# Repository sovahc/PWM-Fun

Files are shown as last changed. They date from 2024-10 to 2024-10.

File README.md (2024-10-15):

# PWM-Fun
PWM fan controller for water cooled PC
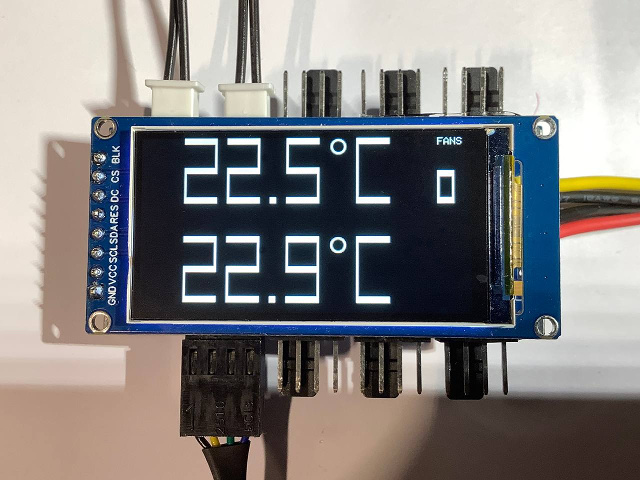
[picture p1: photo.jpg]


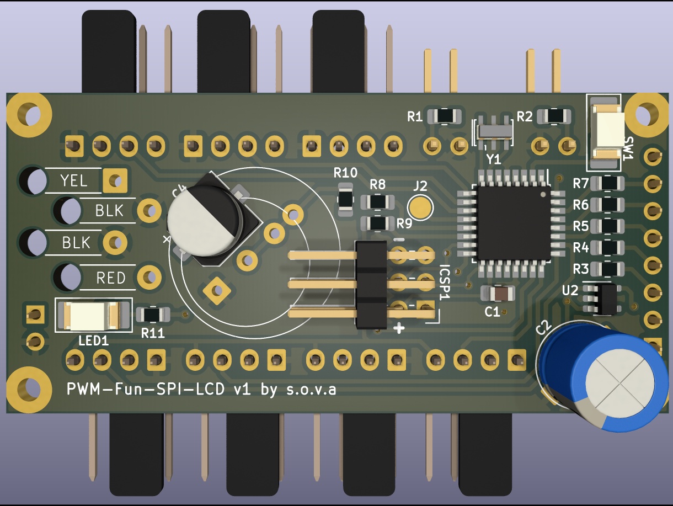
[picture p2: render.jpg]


I didn't find the fan controller cheap and cute, so I made it myself.

For building minimal LCD version of this project you need:
* PCB (use Kicad to export gerber files for manufacturing)
* 170x320 SPI LCD (they are cheap and slow)
* ATMega328 microcontroller
* 2.54mm single row 8 pin male + female connector (I recommend short L7.5 version)
* 2x SMD 10k resistor (R1, R2)
* 7x SMD 220 Ohm resistor (R3 - R9)
* SMD 100 nF capacitor (C1)
* SMD(or not) 4.7 uF capacitor (C2)
* 7x angled PC Fan connector  
* M2.5 screws and nuts for mounting.
* SATA to Molex adapter (Not Molex to SATA!)

Equipment:
* Any AVR programmer (You can use any usb arduino board with sketch ArduinoISP, don't forget to press "Upload Using Programmer")
* Good soldering iron recomended.

You can add buzzer and 500 Ohm resistor if you like.

You can add WS2812 strip if you like.

You can use the ATmega internal oscillator if you are not using the WS2812.

Don't forget to short J1 if you not use U2 (probably you don't need U2)

The fans speed is controlled by the thermal sensor 1. The thermal sensor 2 is set to 50°C alarm. I use it to control the temperature of 12VHPWR connector 🩹

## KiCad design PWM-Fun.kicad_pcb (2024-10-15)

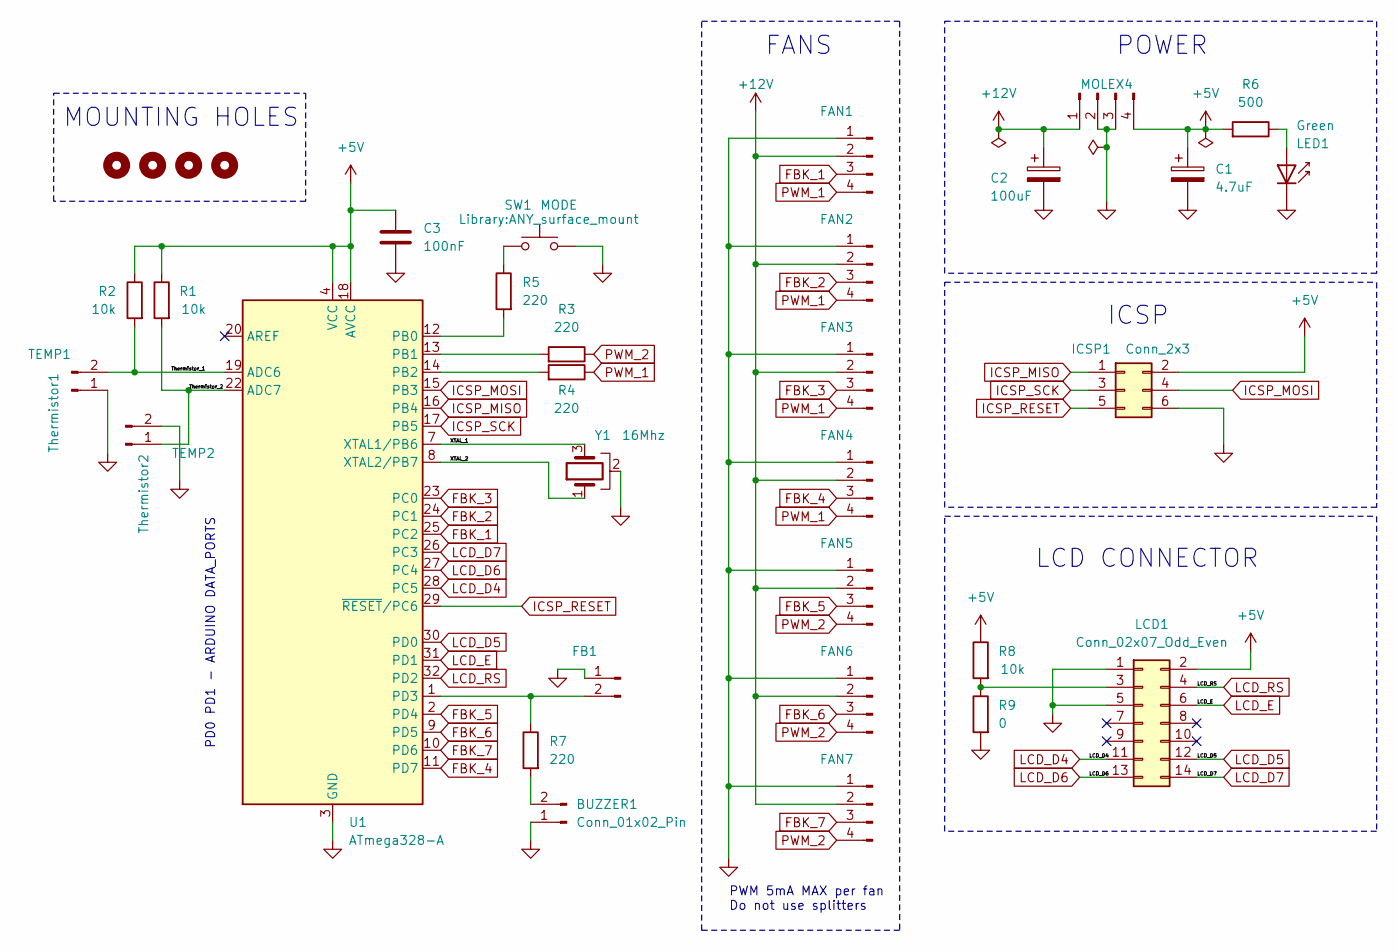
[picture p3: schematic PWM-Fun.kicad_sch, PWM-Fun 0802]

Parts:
BUZZER1: Conn_01x02_Pin; My_buzzer
C1: 4.7uF; Multicap
C2: 100uF; Multicap
C3: 100nF; C_0805_2012Metric_Pad1.18x1.45mm_HandSolder
FAN1, FAN2, FAN3, FAN4, FAN5, FAN6, FAN7: FanPinHeader_1x04_P2.54mm_Vertical_custom
FB1: TO_PC; PinSocket_1x02_P2.54mm_Vertical
H1, H2, H3, H4: MountingHole_Pad; Slot 2.5x1.27
ICSP1: Conn_2x3; PinHeader_2x03_P2.54mm_Horizontal
LCD1: Conn_02x07_Odd_Even; LCD_Connector_2x07_P2.54mm_Vertical
LED1: Green; ANY_surface_mount
MOLEX4: Conn_01x04_Pin; SolderWire-1-2_compact
R1, R2, R8: 10k; R_0805_2012Metric_Pad1.20x1.40mm_HandSolder
R3, R4, R5, R7: 220; R_0805_2012Metric_Pad1.20x1.40mm_HandSolder
R6: 500; R_0805_2012Metric_Pad1.20x1.40mm_HandSolder
R9: 0; R_0805_2012Metric_Pad1.20x1.40mm_HandSolder
SW1: MODE; ANY_surface_mount
TEMP1: Thermistor1; PinHeader_1x02_P2.54mm_Horizontal
TEMP2: Thermistor2; PinHeader_1x02_P2.54mm_Horizontal
U1: ATmega328-A; TQFP-32_7x7mm_P0.8mm
Y1: 16Mhz; Resonator_SMD_Murata_CSTxExxV-3Pin_3.0x1.1mm_HandSoldering

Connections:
+5V: C1.1, C3.1, ICSP1.2, LCD1.2, MOLEX4.4, R1.1, R2.1, R6.2, R8.1, U1.4 (VCC), U1.6 (VCC), U1.18 (AVCC)
+12V: C2.1, FAN1.2, FAN2.2, FAN3.2, FAN4.2, FAN5.2, FAN6.2, FAN7.2, MOLEX4.1
/Thermistor_1: R2.2, TEMP1.2, U1.19 (ADC6)
/Thermistor_2: R1.2, TEMP2.1, U1.22 (ADC7)
/XTAL_1: U1.7 (XTAL1/PB6), Y1.3
/XTAL_2: U1.8 (XTAL2/PB7), Y1.1
FBK_1: FAN1.3, U1.25 (PC2)
FBK_2: FAN2.3, U1.24 (PC1)
FBK_3: FAN3.3, U1.23 (PC0)
FBK_4: FAN4.3, U1.11 (PD7)
FBK_5: FAN5.3, U1.2 (PD4)
FBK_6: FAN6.3, U1.9 (PD5)
FBK_7: FAN7.3, U1.10 (PD6)
GND: BUZZER1.1, C1.2, C2.2, C3.2, FAN1.1, FAN2.1, FAN3.1, FAN4.1, FAN5.1, FAN6.1, FAN7.1, FB1.1, ICSP1.6, LCD1.1, LCD1.5, LED1.1 (K), MOLEX4.2, MOLEX4.3, R9.2, SW1.2, TEMP1.1, TEMP2.2, U1.3 (GND), U1.5 (GND), U1.21 (GND), Y1.2
ICSP_MISO: ICSP1.1, U1.16 (PB4)
ICSP_MOSI: ICSP1.4, U1.15 (PB3)
ICSP_RESET: ICSP1.5, U1.29 (~RESET/PC6)
ICSP_SCK: ICSP1.3, U1.17 (PB5)
LCD_D4: LCD1.11, U1.28 (PC5)
LCD_D5: LCD1.12, U1.30 (PD0)
LCD_D6: LCD1.13, U1.27 (PC4)
LCD_D7: LCD1.14, U1.26 (PC3)
LCD_E: LCD1.6, U1.31 (PD1)
LCD_RS: LCD1.4, U1.32 (PD2)
unnamed: BUZZER1.2, R7.2
unnamed: FB1.2, R7.1, U1.1 (PD3)
unnamed: LCD1.3, R8.2, R9.1
unnamed: LED1.2 (A), R6.1
unnamed: R5.1, SW1.1
unnamed: R5.2, U1.12 (PB0)
unnamed: R3.2, U1.13 (PB1)
unnamed: R4.2, U1.14 (PB2)
PWM_1: FAN1.4, FAN2.4, FAN3.4, FAN4.4, R4.1
PWM_2: FAN5.4, FAN6.4, FAN7.4, R3.1

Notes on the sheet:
MOUNTING HOLES
FANS
ICSP
PD0 PD1 - ARDUINO DATA_PORTS
LCD CONNECTOR
PWM 5mA MAX per fan Do not use splitters
POWER

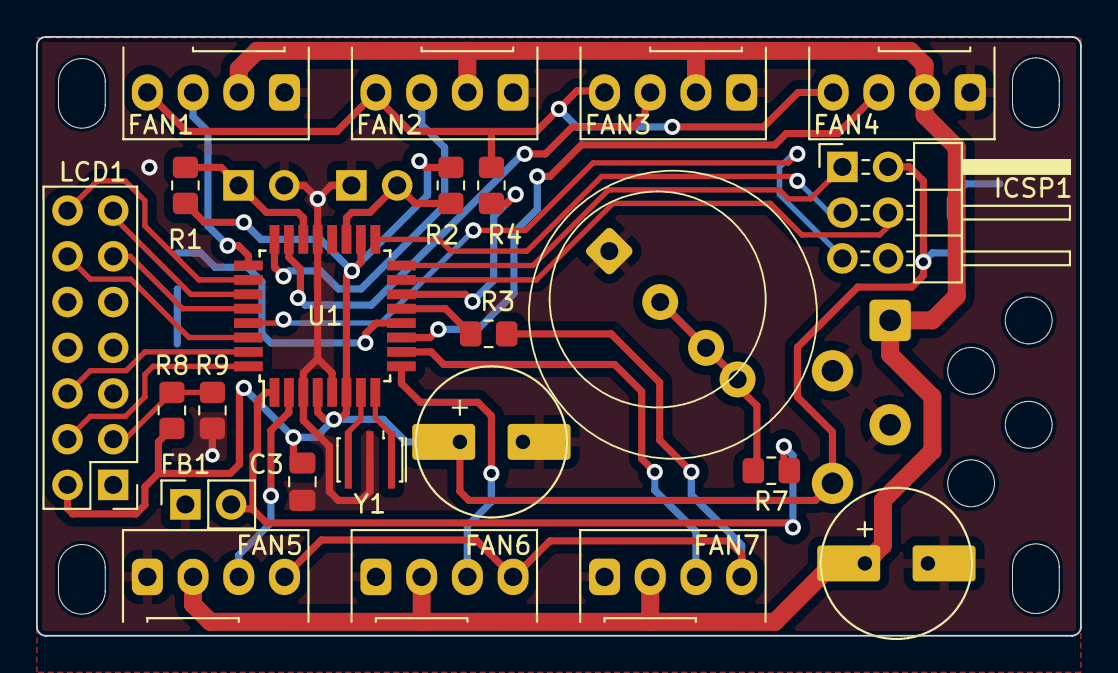
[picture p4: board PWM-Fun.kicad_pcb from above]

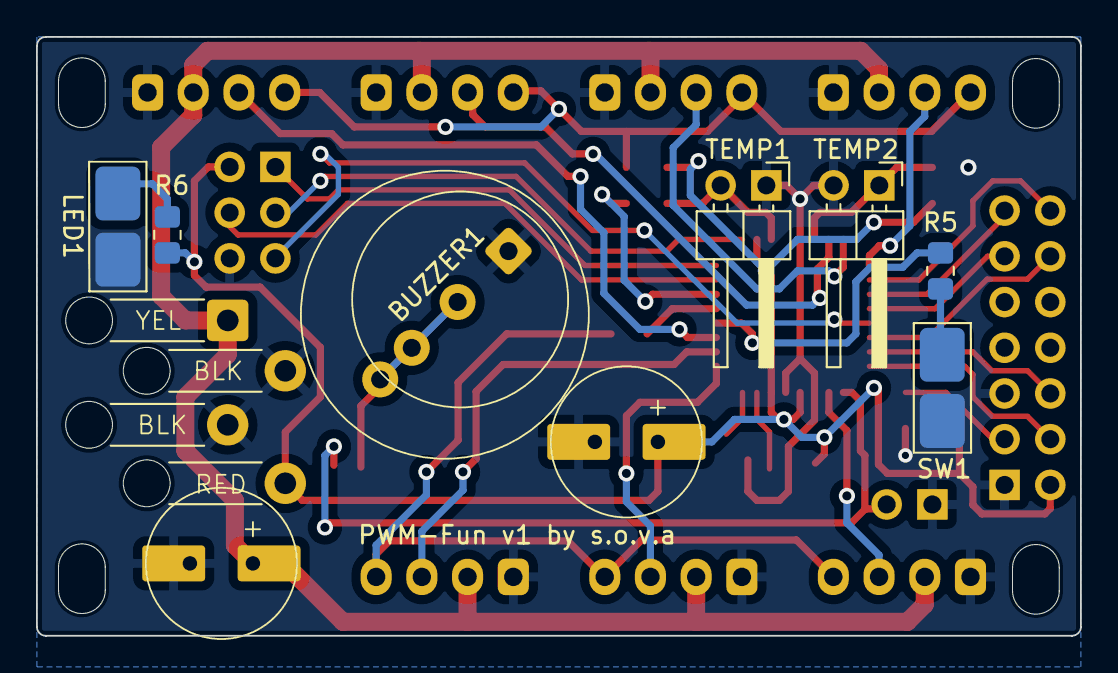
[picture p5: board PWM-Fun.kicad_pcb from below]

Board: 2 copper layers, 58.0 x 33.3 mm, 34 parts (8 on the bottom side), 34 nets.

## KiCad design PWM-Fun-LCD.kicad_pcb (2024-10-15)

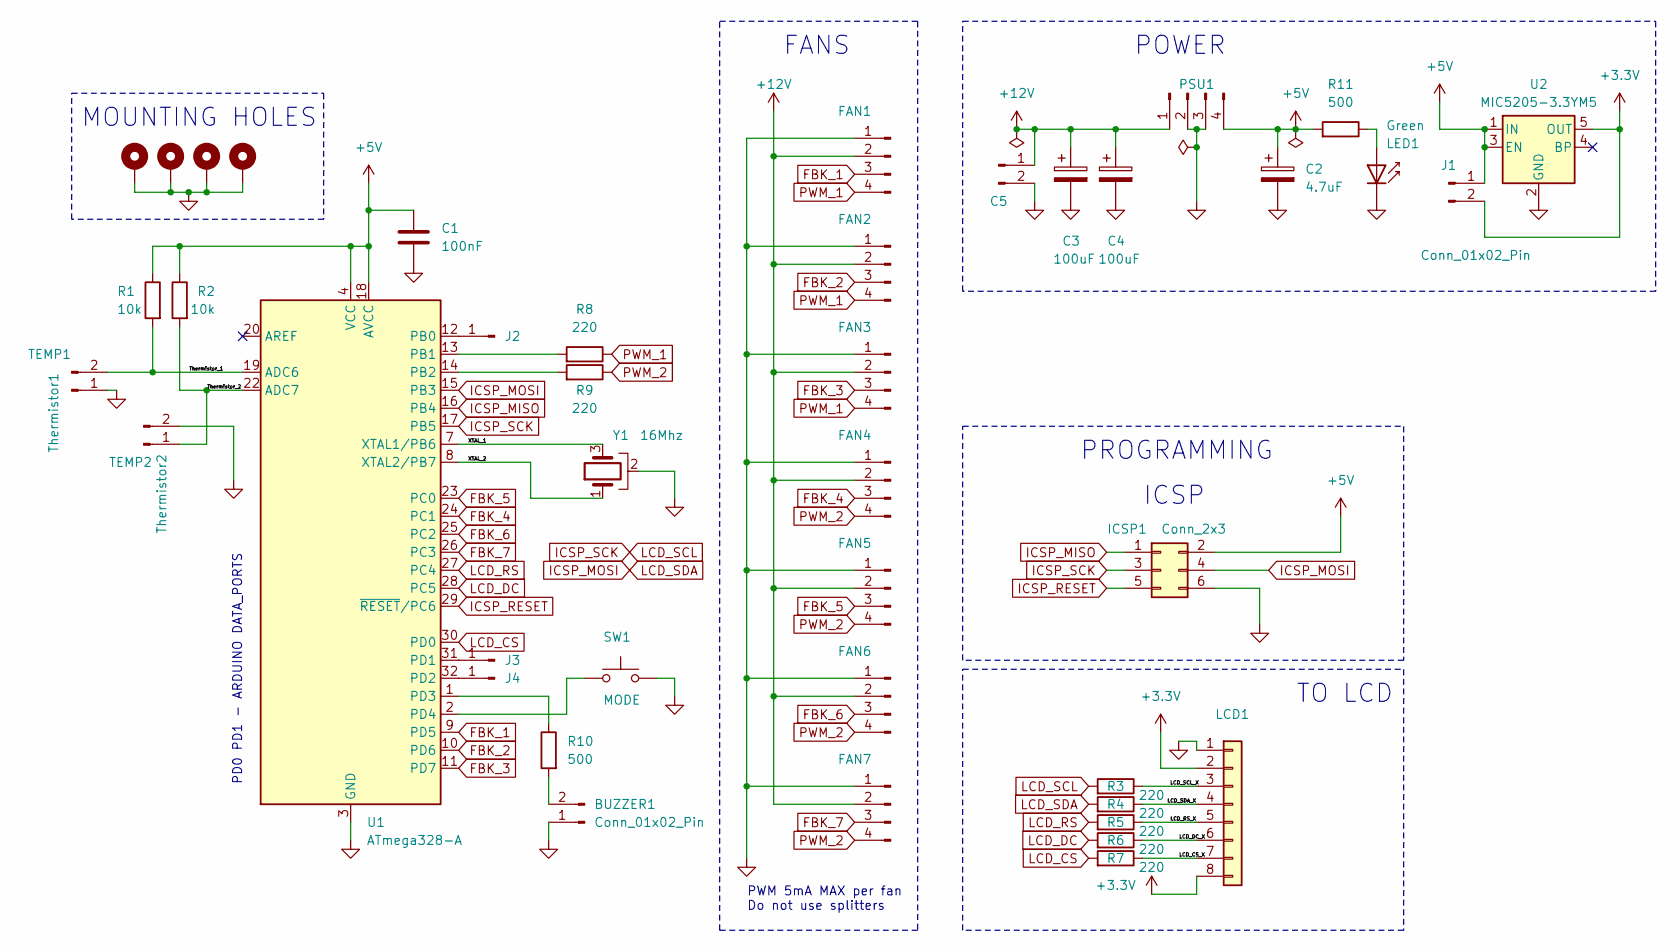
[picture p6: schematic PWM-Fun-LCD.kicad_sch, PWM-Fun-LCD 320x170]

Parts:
BUZZER1: Conn_01x02_Pin; My_buzzer
C1: 100nF; C_0805_2012Metric_Pad1.18x1.45mm_HandSolder
C2: 4.7uF; Multicap
C3, C4: 100uF; CP_Elec_6.3x3.9
C5: TO_PC; PinSocket_1x02_P2.54mm_Vertical
FAN1, FAN2, FAN3, FAN4, FAN5, FAN6, FAN7: FanPinHeader_1x04_P2.54mm_Vertical_custom
H1, H2, H3, H4: MountingHole_Pad; MountingHole_2.2mm_M2_Pad
ICSP1: Conn_2x3; PinHeader_2x03_P2.54mm_Horizontal
J1: Conn_01x02_Pin; SolderJumper-2_P1.3mm_Open_TrianglePad1.0x1.5mm
J2, J3, J4: Unused; TestPoint_Pad_D2.0mm
LCD1: PinSocket_1x08_P2.54mm_Vertical
LED1: Green; ANY_surface_mount
PSU1: Conn_01x04_Pin; SolderWire-1-2_compact
R1, R2: 10k; R_0805_2012Metric_Pad1.20x1.40mm_HandSolder
R3, R4, R5, R6, R7, R8, R9: 220; R_0805_2012Metric_Pad1.20x1.40mm_HandSolder
R10, R11: 500; R_0805_2012Metric_Pad1.20x1.40mm_HandSolder
SW1: MODE; ANY_surface_mount
TEMP1: Thermistor1; my_PinHeader_1x02_P2.54mm_Horizontal
TEMP2: Thermistor2; my_PinHeader_1x02_P2.54mm_Horizontal
U1: ATmega328-A; TQFP-32_7x7mm_P0.8mm
U2: MIC5205-3.3YM5; SOT-23-5
Y1: 16Mhz; Resonator_SMD_Murata_CSTxExxV-3Pin_3.0x1.1mm_HandSoldering

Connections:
+3.3V: J1.2, LCD1.2, LCD1.8, U2.5 (OUT)
+5V: C1.1, C2.1, ICSP1.2, J1.1, PSU1.4, R1.1, R2.1, R11.2, U1.4 (VCC), U1.6 (VCC), U1.18 (AVCC), U2.1 (IN), U2.3 (EN)
+12V: C3.1, C4.1, C5.1, FAN1.2, FAN2.2, FAN3.2, FAN4.2, FAN5.2, FAN6.2, FAN7.2, PSU1.1
/LCD_CS_X: LCD1.7, R7.1
/LCD_DC_X: LCD1.6, R6.1
/LCD_RS_X: LCD1.5, R5.1
/LCD_SCL_X: LCD1.3, R3.1
/LCD_SDA_X: LCD1.4, R4.1
/Thermistor_1: R1.2, TEMP1.2, U1.19 (ADC6)
/Thermistor_2: R2.2, TEMP2.1, U1.22 (ADC7)
/XTAL_1: U1.7 (XTAL1/PB6), Y1.3
/XTAL_2: U1.8 (XTAL2/PB7), Y1.1
FBK_1: FAN1.3, U1.9 (PD5)
FBK_2: FAN2.3, U1.10 (PD6)
FBK_3: FAN3.3, U1.11 (PD7)
FBK_4: FAN4.3, U1.24 (PC1)
FBK_5: FAN5.3, U1.23 (PC0)
FBK_6: FAN6.3, U1.25 (PC2)
FBK_7: FAN7.3, U1.26 (PC3)
GND: BUZZER1.1, C1.2, C2.2, C3.2, C4.2, C5.2, FAN1.1, FAN2.1, FAN3.1, FAN4.1, FAN5.1, FAN6.1, FAN7.1, H1.1, H2.1, H3.1, H4.1, ICSP1.6, LCD1.1, LED1.1 (K), PSU1.2, PSU1.3, SW1.2, TEMP1.1, TEMP2.2, U1.3 (GND), U1.5 (GND), U1.21 (GND), U2.2 (GND), Y1.2
ICSP_MISO: ICSP1.1, U1.16 (PB4)
ICSP_MOSI: ICSP1.4, R4.2, U1.15 (PB3)
ICSP_RESET: ICSP1.5, U1.29 (~RESET/PC6)
ICSP_SCK: ICSP1.3, R3.2, U1.17 (PB5)
LCD_CS: R7.2, U1.30 (PD0)
LCD_DC: R6.2, U1.28 (PC5)
LCD_RS: R5.2, U1.27 (PC4)
unnamed: BUZZER1.2, R10.2
unnamed: J2.1, U1.12 (PB0)
unnamed: J3.1, U1.31 (PD1)
unnamed: J4.1, U1.32 (PD2)
unnamed: LED1.2 (A), R11.1
unnamed: R8.2, U1.13 (PB1)
unnamed: R9.2, U1.14 (PB2)
unnamed: R10.1, U1.1 (PD3)
unnamed: SW1.1, U1.2 (PD4)
PWM_1: FAN1.4, FAN2.4, FAN3.4, R8.1
PWM_2: FAN4.4, FAN5.4, FAN6.4, FAN7.4, R9.1

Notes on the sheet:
MOUNTING HOLES
FANS
PROGRAMMING
ICSP
PD0 PD1 - ARDUINO DATA_PORTS
TO LCD
PWM 5mA MAX per fan Do not use splitters
POWER

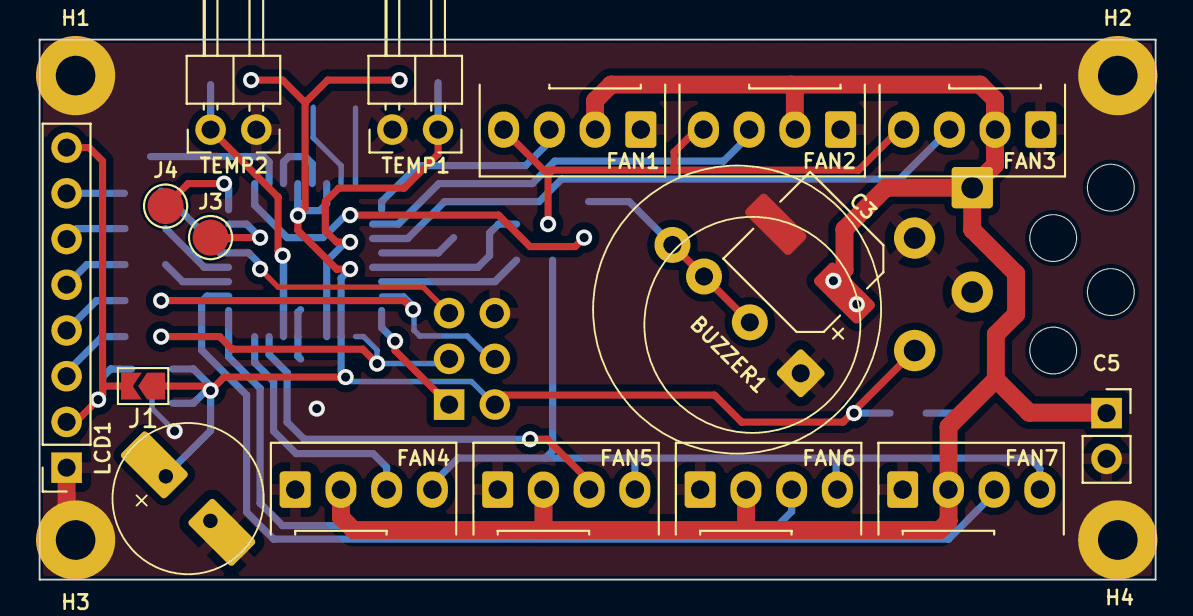
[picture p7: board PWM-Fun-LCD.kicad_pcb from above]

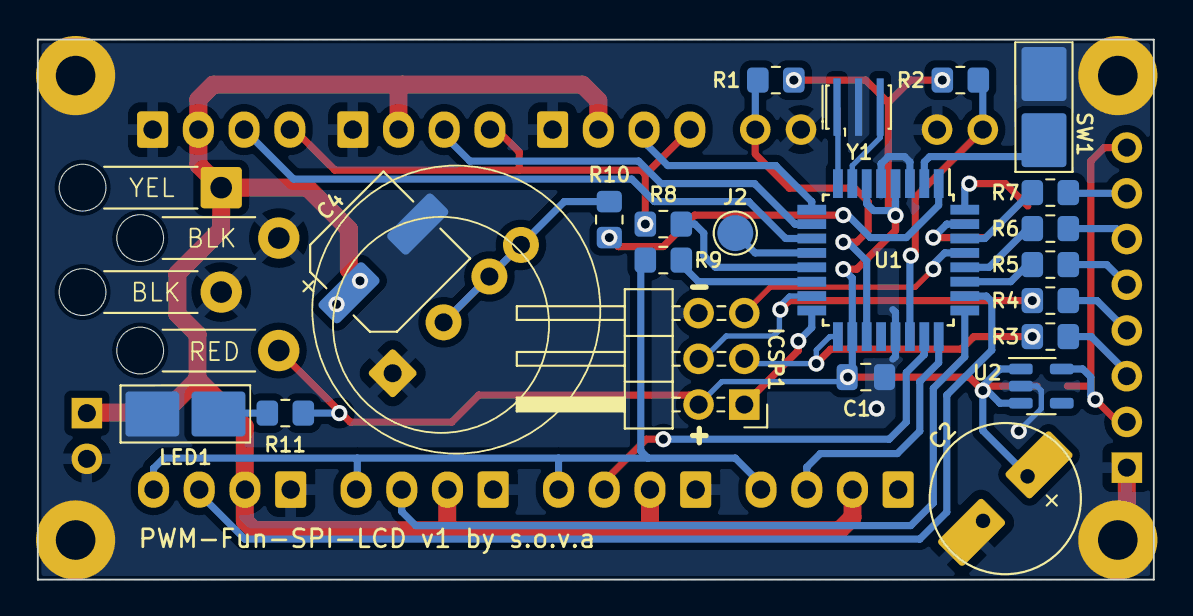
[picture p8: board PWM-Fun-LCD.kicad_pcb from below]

Board: 2 copper layers, 62.0 x 30.0 mm, 42 parts (22 on the bottom side), 38 nets.

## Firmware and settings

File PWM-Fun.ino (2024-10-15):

// This is Atmega328 based PWM fan controller for water cooled PC.

const float thermistor2_alert = 50.0f; // Celisus

#define WS2812_STRIP_CONNECTED false

#if WS2812_STRIP_CONNECTED
  #define TLED_ORDER ORDER_GRB
  #define TLED_CHIP LED_WS2812
  #include "tinyLED.h" // microLED library
tinyLED<0> strip; // port B pin 0 (Arduino pin 8)

void fill_led(uint8_t r, uint8_t g, uint8_t b)
{ for(int i = 0; i < 8; ++i)
    strip.sendRGB(r, g, b);  
}
#else
void fill_led(uint8_t r, uint8_t g, uint8_t b) {}
#endif

const char* error_message = nullptr;

#if true
  #include "LCD_SPI.h"
#else
  #include "LCD_0802.h"
#endif

// PWM pins (cannot be changed)
static const int PIN_PWM_1A = 9;
static const int PIN_PWM_1B = 10;
static const int PIN_PWM_2 = 3;
//

#define ARRAY_SIZE(a) ( sizeof(a)/sizeof(a[0]) )
#define STRINGIZE(x) STRINGIZE2(x)
#define STRINGIZE2(x) #x

struct Fan_curve_point
{ float temperature;
  float pwm;
};

class Fan_curve
{
    Fan_curve_point curve[10];
    int count = 0;

    const char* verify_curve()
    {
      for (int i = 0; i < count; ++i)
      { Fan_curve_point& p = curve[i];

        // Values must be in valid range.
        //if (p.temperature < 0 || p.temperature > 100) return "verify1";
        if (p.pwm < 0 || p.pwm > 1) return "verify2";

        if (i < 1) continue;

        Fan_curve_point& pp = curve[i - 1];

        // The points should be given in ascending order.
        if (p.temperature <= pp.temperature) return "verify3"; // "<=" - avoid division by zero
        if (p.pwm < pp.pwm) return "verify4";
      }
      return nullptr; // no error
    }

  public:
    void add_point(float temperature, float pwm)
    {
      if (count >= ARRAY_SIZE(curve))
      { error_message = "add_point";
        return;
      }

      curve[count].temperature = temperature;
      curve[count].pwm = pwm;
      ++count;

      // Automatic curve verification
      if(error_message == nullptr)
      { error_message = verify_curve();
      }
    }

    float calculate_pwm(float temperature)
    {
      if (count <= 0) return 1.0; // Full fan speed if no points defined.

      for(int i = 0; i < count-1; ++i)
      {
        if(temperature >= curve[i].temperature &&
          temperature <= curve[i+1].temperature) // in range
        {
          // interpolate

          Fan_curve_point& a = curve[i];
          Fan_curve_point& b = curve[i+1];
          float interpolation_factor = (temperature - a.temperature) / (b.temperature - a.temperature);
          
          return a.pwm + (b.pwm - a.pwm) * interpolation_factor;
        }
      }

      error_message = "no range";
      return 1.0;
    }
};

Fan_curve fan_curve;

void set_fan_curve()
{ // The minimum duty cycle is 20% according to Intel. Noctua fans can operate from 0%

#if false // Curve for testing the device
  fan_curve.add_point(-300, 0); // Don't remove this point
  fan_curve.add_point(27, 0);
  fan_curve.add_point(27.01, 0.9);
  fan_curve.add_point(300.0, 1.0); // Don't remove this point
#else
  fan_curve.add_point(-300, 0); // Don't remove this point
  fan_curve.add_point(30, 0);
  fan_curve.add_point(30.01, 0.2);
  fan_curve.add_point(60.0, 1.0);
  fan_curve.add_point(300.0, 1.0); // Don't remove this point
#endif
}

class Pwm_output_1
{
    static inline float clamp_01(float f)
    { if (f < 0) return 0;
      if (f > 1) return 1;
      return f;
    }

  public:
    static void initialize()
    {
      // https://fdossena.com/?p=ArduinoFanControl/i.md

      // Enable outputs for Timer 1
      pinMode(PIN_PWM_1A, OUTPUT);
      pinMode(PIN_PWM_1B, OUTPUT);

      // Set PWM frequency to about 25khz on pins 9,10 (timer 1 mode 10, no prescale, count to 320)
      TCCR1A = (1 << COM1A1) | (1 << COM1B1) | (1 << WGM11);
      TCCR1B = (1 << CS10) | (1 << WGM13);
      ICR1 = 320;
      OCR1A = 0;
      OCR1B = 0;
    }

    static void set_pin9_duty(float f)
    { OCR1A = (uint16_t)(320 * clamp_01(f));
    }

    static void set_pin10_duty(float f)
    { OCR1B = (uint16_t)(320 * clamp_01(f));
    }
};

class Thermistor
{
    // Values from the datasheet
    static const int R_25 = 10000; // Ω
    static const int B_value = 3977; // K
    //

  public:
    static float calculate_temperature(float analog)
    {
      const int VCC = 5;
      const int SERIAL_R = 10000; // thermistor serial resistor in Ohms
      const float T0 = 25 + 273.15; // thermistor T0 in Kelvins

      float thermistor_V = (5.00 / 1023.00) * analog;
      float resistor_V = VCC - thermistor_V;
      float thermistor_R = thermistor_V / (resistor_V / SERIAL_R);

      float ln = log(thermistor_R / R_25);
      float temperature = (1 / ((ln / B_value) + (1 / T0)));

      temperature -= 273.15;// to Celsius
      return temperature;
    }
};

class Fan
{
    int counter;
    unsigned long last_feedback_time;
    unsigned long base_feedback_time;

  public:
    int rpm;
    unsigned long total_feedback;

    void feedback() // called from interrupt
    {
      ++counter;
      ++total_feedback;
      last_feedback_time = millis();
    }

    void recalculate_rpm()
    {
      auto delta = last_feedback_time - base_feedback_time;

      rpm = counter * 60000 / 4 / delta; // two pulses per revolution * rise and fall = 4

      base_feedback_time = last_feedback_time;
      counter = 0;
    }
};

class Fans_feedback
{
    const int PORT_C_PIN0 = 14;

    const byte feedback_pins_C[FAN_FEEDBACK_PINS_C_COUNT] = FAN_FEEDBACK_PINS_C;
    const byte feedback_pins_D[FAN_FEEDBACK_PINS_D_COUNT] = FAN_FEEDBACK_PINS_D;

    static const int FANS_COUNT = ARRAY_SIZE(feedback_pins_C) + ARRAY_SIZE(feedback_pins_D);

    bool pin_state_C[ ARRAY_SIZE(feedback_pins_C) ];
    bool pin_state_D[ ARRAY_SIZE(feedback_pins_D) ];

  public:
    Fan fans[FANS_COUNT];

    void recalculate_rpm()
    {
      for (int i = 0; i < ARRAY_SIZE(fans); ++i)
      {
        fans[i].recalculate_rpm();
      }
    }

    inline void isr_port_c() // called from interrupt
    {
      for (int i = 0; i < ARRAY_SIZE(feedback_pins_C); ++i)
      { const int mask = 1 << (feedback_pins_C[i] - PORT_C_PIN0);
        bool b = PINC & mask;
        if (pin_state_C[i] != b)
        { pin_state_C[i] = b;

          fans[i].feedback();
        }
      }
    }

    inline void isr_port_d() // called from interrupt
    {
      for (int i = 0; i < ARRAY_SIZE(feedback_pins_D); ++i)
      { const int mask = 1 << feedback_pins_D[i];
        bool b = PIND & mask;
        if (pin_state_D[i] != b)
        { pin_state_D[i] = b;

          fans[i + ARRAY_SIZE(feedback_pins_C)].feedback();
        }
      }
    }

    void initialize()
    {
      // Activate PCINT

      for (auto pin : feedback_pins_C)
      { pinMode(pin, INPUT_PULLUP);
        PCMSK1 |= 1 << (pin - PORT_C_PIN0);
      }

      for (auto pin : feedback_pins_D)
      { pinMode(pin, INPUT_PULLUP);
        PCMSK2 |= 1 << pin;
      }

      PCICR |= B00000010; // activate the interrupts of the PC port
      PCICR |= B00000100; // activate the interrupts of the PD port
    }

} fans_feedback;

// Interrupts cannot be used inside a class, so we redirect them.
ISR (PCINT2_vect)
{ fans_feedback.isr_port_d();  // PORTD (Arduino pins: D0 to D7)
}
ISR (PCINT1_vect)
{ fans_feedback.isr_port_c();  // PORTC (Arduino pins: D14 to D22)
}

void setup()
{
  My_display::initialize(); // Display initial message

  Pwm_output_1::initialize();

  // Initially start the fans for a short time.
  Pwm_output_1::set_pin9_duty(0.5f);
  Pwm_output_1::set_pin10_duty(0.5f);

  fans_feedback.initialize();

  delay(500);

  //error_message = "TEST_" STRINGIZE(__LINE__); // Error message test

  set_fan_curve();

  short_beep();
}

void short_beep()
{
  tone(PIN_PWM_2, 1000);
  delay(200);
  noTone(PIN_PWM_2);
}

void loop()
{
  if (error_message != nullptr)
  {
    // If an error occurs, turn on all fans to full speed.
    Pwm_output_1::set_pin9_duty(1);
    Pwm_output_1::set_pin10_duty(1);

    My_display::display_error("ERROR", error_message);

    digitalWrite(LED_BUILTIN, HIGH);
    fill_led(100,100,0);
    short_beep();
    digitalWrite(LED_BUILTIN, LOW);
  }
  else
  {
    digitalWrite(LED_BUILTIN, HIGH);
    delay(50);
    digitalWrite(LED_BUILTIN, LOW);

    // Averaging thermistors samples to eliminate noise
    const int num_samples = 500;

    float average1 = 0;
    float average2 = 0;

    for (int i = 0; i < num_samples; ++i)
    { average1 += analogRead(A6); // thermistor pin number
      average2 += analogRead(A7); // thermistor pin number
      
      delay(1);
    }
    average1 /= num_samples;
    average2 /= num_samples;

    float t1 = Thermistor::calculate_temperature(average1);
    float t2 = Thermistor::calculate_temperature(average2);

    My_display::print_temperature(0, t1, average1 < 10);
    My_display::print_temperature(1, t2, average2 < 10);

    if(t2 < thermistor2_alert)
    { 
      float pwm = fan_curve.calculate_pwm(t1);

      Pwm_output_1::set_pin9_duty(pwm);
      Pwm_output_1::set_pin10_duty(pwm);
    }
    else
    { Pwm_output_1::set_pin9_duty(1);
      Pwm_output_1::set_pin10_duty(1);
      fill_led(100,0,0);
      short_beep();
    }

    fans_feedback.recalculate_rpm();
  
    int running_fans = 0;
    for(auto fan : fans_feedback.fans)
    { if(fan.rpm > 0) ++running_fans;
    }

    My_display::print_fans_count(running_fans);

    //auto rpm0 = fans_feedback.fans[0].rpm;

    fill_led(1,1,2);
  }
}

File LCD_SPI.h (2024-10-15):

#include <Adafruit_GFX.h> // graphics library
#include <Adafruit_ST7789.h> // library for this display
#include <SPI.h>

#define FAN_FEEDBACK_PINS_C_COUNT 4
#define FAN_FEEDBACK_PINS_D_COUNT 3
#define FAN_FEEDBACK_PINS_C { 15, 14, 16, 17 }
#define FAN_FEEDBACK_PINS_D { 5, 6, 7 }

class TFT
{
  Adafruit_ST7789 tft = Adafruit_ST7789(0, 19, 18); // cs, dc, rs
public:
  static const int W = 320;
  static const int H = 170;

  static const uint16_t WHITE  = ST77XX_WHITE;
  static const uint16_t BLACK  = ST77XX_BLACK;
  static const uint16_t RED    = ST77XX_RED;
  static const uint16_t YELLOW = ST77XX_YELLOW;
  // ______________________________RRRRRGGGGGGBBBBB // 565
  static const uint16_t GRAY      = 0b0111101111101111; 
  static const uint16_t DARK_GRAY = 0b0000100001100001;
  static const uint16_t BLUE  = ST77XX_BLUE;

  void initialize()
  { tft.init(H, W, SPI_MODE0);
    //tft.setSPISpeed(800000); // SLOW
    tft.setRotation(3);
    //tft.fillScreen(DARK_GRAY);
    tft.fillScreen(BLACK);
    tft.setTextWrap(false);
  }

  void fill_rectangle(int16_t x, int16_t y, int16_t w, int16_t h, uint16_t color)
  { tft.fillRect(x, y, w, h, color);
  }

  void draw_text(int16_t x, int16_t y, int16_t w, int16_t h, uint16_t color, uint16_t background, const char* text)
  { tft.setTextSize(1);
    tft.setTextColor(color, background);
    tft.setCursor(x, y);
    tft.print(text);
  }

  #define MAKE_RGB565(r, g, b) ((r << 11) | (g << 5) | (b))

  uint16_t blend_rgb565(uint16_t a, uint16_t b, uint8_t Alpha)
  {
    const uint8_t invAlpha = 255 - Alpha;

    uint16_t A_r = a >> 11;
    uint16_t A_g = (a >> 5) & 0x3f;
    uint16_t A_b = a & 0x1f;

    uint16_t B_r = b >> 11;
    uint16_t B_g = (b >> 5) & 0x3f;
    uint16_t B_b = b & 0x1f;

    uint32_t C_r = (A_r * invAlpha + B_r * Alpha) / 255;
    uint32_t C_g = (A_g * invAlpha + B_g * Alpha) / 255;
    uint32_t C_b = (A_b * invAlpha + B_b * Alpha) / 255;

    return MAKE_RGB565(C_r, C_g, C_b);
  }

  void bublic(int16_t x0, int16_t y0, int16_t r1, int16_t r2, uint16_t color, uint16_t background)
  { 
    // not optimized
    auto A = r1*r1;
    auto B = (r1-1)*(r1-1);
    auto C = r2*r2;
    auto D = (r2-1)*(r2-1);

    if(r2 < 0)
    { C = -C;
      D = -D;
    }

    for(int16_t y = -r1; y < r1; ++y)
      for(int16_t x = -r1; x < r1; ++x)
      { 
        uint16_t c;
        auto d = x*x + y*y;
        
        if(d > A) c = background;
        else if(d > B) c = blend_rgb565(background, color, map(d, B, A, 255, 0));
        else if(d > C) c = color;
        else if(d > D) c = blend_rgb565(background, color, map(d, D, C, 0, 255));
        else c = background;

        tft.drawPixel(x0+x, y0+y, c);
      }
  }
} tft;

static const uint8_t D0_9[] = // Rotated CCW
{
  0b11111, // 0
  0b10001,
  0b11111,

  0b11111, // 1
  0b00000,
  0b00000,

  0b11101, // 2
  0b10101,
  0b10111,

  0b11111, // 3
  0b10101,
  0b10101,

  0b11111, // 4
  0b00100,
  0b11100,

  0b10111, // 5
  0b10101,
  0b11101,

  0b10111, // 6
  0b10101,
  0b11111,

  0b11111, // 7
  0b10000,
  0b10000,

  0b11111, // 8
  0b10101,
  0b11111,

  0b11111, // 9
  0b10101,
  0b11101,
};

class Big_digits
{
  static const int w1 = 2;  
  static const int h1 = 6;
  static const uint16_t color = 0xFFff;
  static const uint16_t background = 0;

  static int draw_digit(char c, int16_t x, int16_t y, int16_t w, int16_t h, bool draw_holes)
  { 
    uint8_t b1, b2, b3;

    if(c >= '0' && c <= '9')
    { 
      int offset = (c - '0') * 3;

      b1 = D0_9[offset+2];
      b2 = D0_9[offset+1];
      b3 = D0_9[offset+0];
    }
    else if(c == ' ')
    { b1 = b2 = b3 = 0;      
    }
    else if(c == 'C')
    { b3 = 0b10001;
      b2 = 0b10001;
      b1 = 0b11111;
    }
    else if(c == '-')
    { b3 = 0b00100;
      b2 = 0b00100;
      b1 = 0b00100;
    }
    else if(c == '\'')
    {
#if false
        // squared °
        w /= 2;
        if(draw_holes) tft.fill_rectangle(x, y+h/2, w, h/2, background);
        h /= 2;
        b1 = 0b11100;
        b2 = 0b10100;
        b3 = 0b11100;
#else
        // round antialiased °
        w /= 2;
        if(draw_holes) tft.fill_rectangle(x, y+w, w, h-w, background);
        tft.bublic(x+w/2, y+w/2, w/2, w/2-w1, color, background);
        return w;
#endif
    }
    else if(c == '.')
    { 
#if true
      // square dot
      auto r = h1;
      if(draw_holes) tft.fill_rectangle(x, y, r, h-r, background);
      tft.fill_rectangle(x, y+h-r, r, r, color);
      return r;
#else
      // round dot
      auto r = h1;
      if(draw_holes) tft.fill_rectangle(x, y, r, h-r, background);
      tft.bublic(x+r/2, y+h-r/2, r/2, -1, color, background);
      return r;
#endif
    }

    int16_t w2 = w - w1 - w1;
    int16_t h2 = h - h1 - h1 - h1;
    h2 /= 2;

    for(int j = 0; j < 5; ++j)
    { int bit = 4-j;
      bool s1 = (b1 >> bit) & 1;
      bool s2 = (b2 >> bit) & 1;
      bool s3 = (b3 >> bit) & 1;

      int16_t h = j & 1 ? h2 : h1;

      tft.fill_rectangle(x,       y, w1, h, s1 ? color : background);
      if((j != 1 && j != 3) || draw_holes) //
      tft.fill_rectangle(x+w1,    y, w2, h, s2 ? color : background);
      tft.fill_rectangle(x+w1+w2, y, w1, h, s3 ? color : background);

      y += h;
    }

    return w;
  }
public:
  static void draw(int x, int y, int w, int h, int wspace, char* text, bool draw_holes)
  {
    for(int i = 0; text[i]; ++i)
    { x += draw_digit(text[i], x, y, w, h, draw_holes);
      if(draw_holes) tft.fill_rectangle(x, y, wspace, h, Big_digits::background);
      x += wspace;
    }
  }
};

class My_display
{
  static const int W = 320;
  static const int H = 170;

  static char tmp[0x20];

  public:
    static void initialize()
    {
        tft.initialize();
    }

    static void print_temperature(int line, float t, bool none)
    {
      const int wspace = 10;
      const int hspace = 32;
      const int w = 32;
      const int h = 64;
      int x = 0;
      int y = line * (h + hspace);

      if(t >= -90 && t < 90)
      { dtostrf(t, 5, 1, tmp);
        strcat(tmp, "'C");
        Big_digits::draw(x, y, w, h, wspace, tmp, false);
      }
      //else
      //  strcpy(tmp, "---.-");
    }

    static void print_fans_count(int count)
    {
      int R = 32;
      int x = TFT::W - 32;
      tft.draw_text(x, 0, R, R, TFT::WHITE, TFT::BLACK, "FANS");
      sprintf(tmp, "%d", count);
      Big_digits::draw(x, R, R/2, R, 0, tmp, true);
    }

    static void display_error(const char* m1, const char* m2)
    { 
      tft.draw_text(0, TFT::H-32, TFT::W, 16, TFT::YELLOW, TFT::RED, m1);
      tft.draw_text(0, TFT::H-16, TFT::W, 16, TFT::YELLOW, TFT::RED, m2);
    }
};

char My_display::tmp[] = "";
